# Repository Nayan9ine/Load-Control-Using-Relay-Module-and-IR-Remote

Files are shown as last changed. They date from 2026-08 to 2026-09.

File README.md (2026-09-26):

# Load-Control-Using-Relay-Module-and-IR-Remote 
 
<p align="right">-By Nayan Ag</p>
Created a load control system in which load connected to relay module is turned ON or OFF on entering a password with IR based remote.Built on arduin UNO R3 clone using CH340 chip.
<br><br>
Compo used: IR Receiver; Arduino UNO CH340; Relay Module; Remote with IR transmitter; LCD with I2C ;Load; Jumper cables and 5v cable.

<table>
  <tr>
    <td>
    <br>  <div  align="center"><sub><i> Fig1:Setup Box</i></sub></div>
</td>
    <td>
    <br>  <div  align="center"><sub><i> Fig2: IR receiver on Setup Box</i></sub></div>
</td>
    <td>
    <br><div align="center"><sub><i> Fig3: IR receiver Desoldered</i></sub></div>
</td>
  </tr>
</table>

IR receiver was salvaged off from old dish tv setup box . Has 3 pins with signal,gnd,power starting from left to right respectively. Required a lot of heat and flux to de-solder, ultimately leading to a pin breaking. I soldered jumper cables hastily to it and used shrink tubes. 
<br>

<table>
  <tr>
    <td>
    <br>  <div  align="center"><sub><i> Fig4: IR Receiver</i></sub></div>
</td>
    <td>
    <br>  <div  align="center"><sub><i> Fig5: LDO on Setup Box</i></sub></div>
</td>
    <td>
    <br><div align="center"><sub><i> Fig6: LD1117AG ADA TBTQ</i></sub></div>
</td>
  </tr>
</table>
Finding IR Polarity: Since the setup box wasn’t working, I couldn’t directly measure using multimeter. So I found the component responsible for stepping down which is usually kept near for EMI reduction which is shown in the picture LD1117AG ADA TBTQ. It is a Low Dropout (LDO) linear positive voltage regulator manufactured by UTC (Unisonic Technologies). I compared the connection of IR and LDO with LDO and Barrel jack Input of the circuit. Ground was common to all and the one pin of IR not showing any continuity with LDO was the signal pin hence remains the power pin.<br><br>
Using Library: Used IRremote library by Shirriff, z3t0, ArminJo (https://github.com/Arduino-IRremote/Arduino-IRremote). The library can detect numerous protocols used for communication by IR. Standard rgb light control Remote was used that uses NEC protocol. The library helped identify signal protocol and command code for each button pressed.
<br><br>

<p align="center">
  
   <div align="center"><sub><i> Fig7:Finding Remote Codes</i></sub></div>
</p>   


<div align="center"><sub><i> Fig8:NEC Protocol Used by Remote</i></sub></div>
<br>
Code was adjusted so that it integrates relay, LCD and assigning buttons values with numbers and letters. Removed or commented various sections of original code that was unnecessary after I found out my remote’s protocol.

<br><br>
<p align="center"><br><sub><i>Fig9:RGB Remote</i></sub></p>

<br><br>

<p align="center"><sub><i>Fig10:Remote Button Codes</i></sub></p>

<br><br>
2 passwords declared in code one to turn relay on and other to turn off. Delay() of any value was causing timing issue hence leading to frozen response of lcd or ir. Baud rate of 115200 was utilized. Code only uploads when set back to 9600 for some reason and then turned back to 115200(I think it has something to do with CH340 chip). Millis() was used to debounce the buttons. LCD with I2C used to show the status of relay and password entered. Backlight pins connected with 220ohm resistor and also LCD was supplied with separate 5v to reduce current draw.LCD connected with separate source with gnd common for both ext src and Arduino as sda and sdl do require gnd for reference.A USB A plug was stripped and power and gnd wire connected to IR.

<br>
<table>
  <tr>
    <td>
    <br>  <div  align="center"><sub><i> Fig11 :5v USB A Plug</i></sub></div>
</td>
    <td>
    <br>  <div  align="center"><sub><i> Fig12 :5v USB A Plug</i></sub></div>
</td>
  </tr>
</table>

Current req: relay: 70-80mA per channel to energize the coil and 2-20mA to power the IR led in optocoupler, LCD backlight: 20-50mA, Arduino can provide : 400-450mA by USB ,500-800 by barrel jack (7v-12v).IR receiver 3.3v: 0.4-1.5ma on standby and 3-5mA at peak. During switching of relay rapid current burst occurs that causes fluctuation in LCD causing dim text appearance (due to voltage drop?). To counter that capacitor can be used to be placed in parallel and delayed activation of LCD relay status indicator or in my case I used a totally separate source. 

<br><br>

<br><p align="center"> <sub><i>Fig13: Entire Setup (1)</i></sub>

<br><br>

<p align="center"> <sub><i>Fig14: Entire Setup (2)</i></sub></p>

<br>
<table>
  <tr>
    <td>
    <br>  <div  align="center"><sub><i> Fig15 :Turning ON</i></sub></div>
</td>
    <td>
    <br>  <div  align="center"><sub><i> Fig16 :Bulb is ON</i></sub></div>
</td>
  </tr>
</table>

<table>
  <tr>
    <td>
    <br>  <div  align="center"><sub><i> Fig17 :Turning OFF/i></sub></div>
</td>
    <td>
    <br>  <div  align="center"><sub><i> Fig18 :Bulb OFF</i></sub></div>
</td>
  </tr>
</table>

<table>
  <tr>
    <td>
    <br>  <div  align="center"><sub><i> Fig19 :Wrong Pass Used</i></sub></div>
</td>
    <td>
    <br>  <div  align="center"><sub><i> Fig20 :"RE-ENTER" Displayed</i></sub></div>
</td>
  </tr>
</table>
Kicad Document Images:<br>
Relay module was extracted from (https://github.com/ampnics/Relay-Module-HW-Design).<br>
Screenshot (1045)<br>
Screenshot (1042)<br>
Screenshot (1044)<br>
Screenshot (1043)
<br>
WHAT I LEARNED: Serial.println(F("2")); use of F? F stores memory in Flash instead of using the 2kb SRAM (Save Dynamic Memory) in Arduino UNO and as the code prints a lot of static texts we use flash memory. Variables that change shouldn’t be placed in flash as they need to be in SRAM to be updated.
<br><br>
Flash memory is permanent memory stored in Arduino. It stores the code even when unplugged. Static Variables stored in flash using F() macro.
<br><br>
In SRAM: there is stack and heap in a single memory column. Stack stores function call names and local variables and grows downwards. Heap stores dynamically stored data and grows upward. When memory gets full (called ‘stack overflow’) they both collide into each other and try overwriting each other causing random Arduino reboots and garbage outputs.
<br><br>
Possible Updates: password using cloud/wifi; buzzer integration for audio feedback; circuit need to be made cleaner.

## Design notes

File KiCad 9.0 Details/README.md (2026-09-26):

This file includes what was learnt during PCB making process in KiCad.
---
MADE ARDUINO SHIELD FOR LOAD CONTROL which has relay module IR receiver and LCD display embedded on it with a pot to control brightness.<br><br>
->Learnt how to adjust arduino shield boundary layer to fit in components.<br><br>
->How to use VIAS,Net Labels, Power FLags<br><br>
->power GND symbols act as global labels so symbols with same name so get connected electrically. <br><br>
->re matching pin reference numbers to their footprints<br><br>
->Arduino sheild template was used, the entire boundary was fixed in one place.Was unable to expand the area to put my components in. Learnt about the "locked" feature and disabled it by using Appearance tab and Selection Filter.  <br><br>
->used fillet lines to round up sharp wire edges.<br><br>
->to draw board outline: appearance->layers->Edge.Cuts -> choose drawing line or shape etc.<br><br>
->changing sda/scl pins from digital to analog side in order for better routing<br><br>
->using analog pin as digital for IR receiver for better routing<br><br>
-> can keep signal traces (i2c scl sda) thin but keep them away from high freq signals (buck converter)
or relay module as they create heavy EMI. Never run them parallel to relay lines, cross only at 90 degrees to relay lines)<br><br>
->signal lines: 0.2mm Power lines:0.4mm GND lines: 0.6mm<br><br>
Appropriate Components Found:<br><br>
-> RELAY MODULE DESIGN EXTRACTED from: (https://github.com/ampnics/Relay-Module-HW-Design) when copy-pasted from original schematic the resulting pcb desin was jumbled up so directly copy-pasted PCB design and chenaged the reference name to match the schematic so duplicate relay components won't be created again. <br><br>  
->The LCD I2C component I was able to find (EA T123X-I2C)  was different than what was used in the project. It needed 2 4.7k Ohm pull up resistors for SDA,SCL. Has 2 additional pins for adjusting display contrast (Vo and Vlcd). The contrast was controlled by a potentiometer with Vlcd connected to gnd and 3rd pin of pot. 2nd pin to Vo and 1st to Vdd (5v).
<br><br>
->Added 2 pwr flags on Vo and Vdd as kicad ERC was throwing "input power pins not connected to source" error.<br><br>
->made several connections using NET LABELS to avoid messy wiring.<br><br>
->added no connect flags on pins not being used.<br><br>
-> Mounting holes added to show LCD external 5V supply and AC load connection to relay thorugh a LAMP symbol.<br><br>
->Since GND pins in arduino shield are assumed to be internally connected, KiCad ERC throws "No connection" error and DRC shows unecessary ratnets. So I had to change the name of various GND symbols and some labelled as No Connect.<br><br>
->For smd resistors only traces in front can get connected so used vias to turn back trace into front then connect to smd.

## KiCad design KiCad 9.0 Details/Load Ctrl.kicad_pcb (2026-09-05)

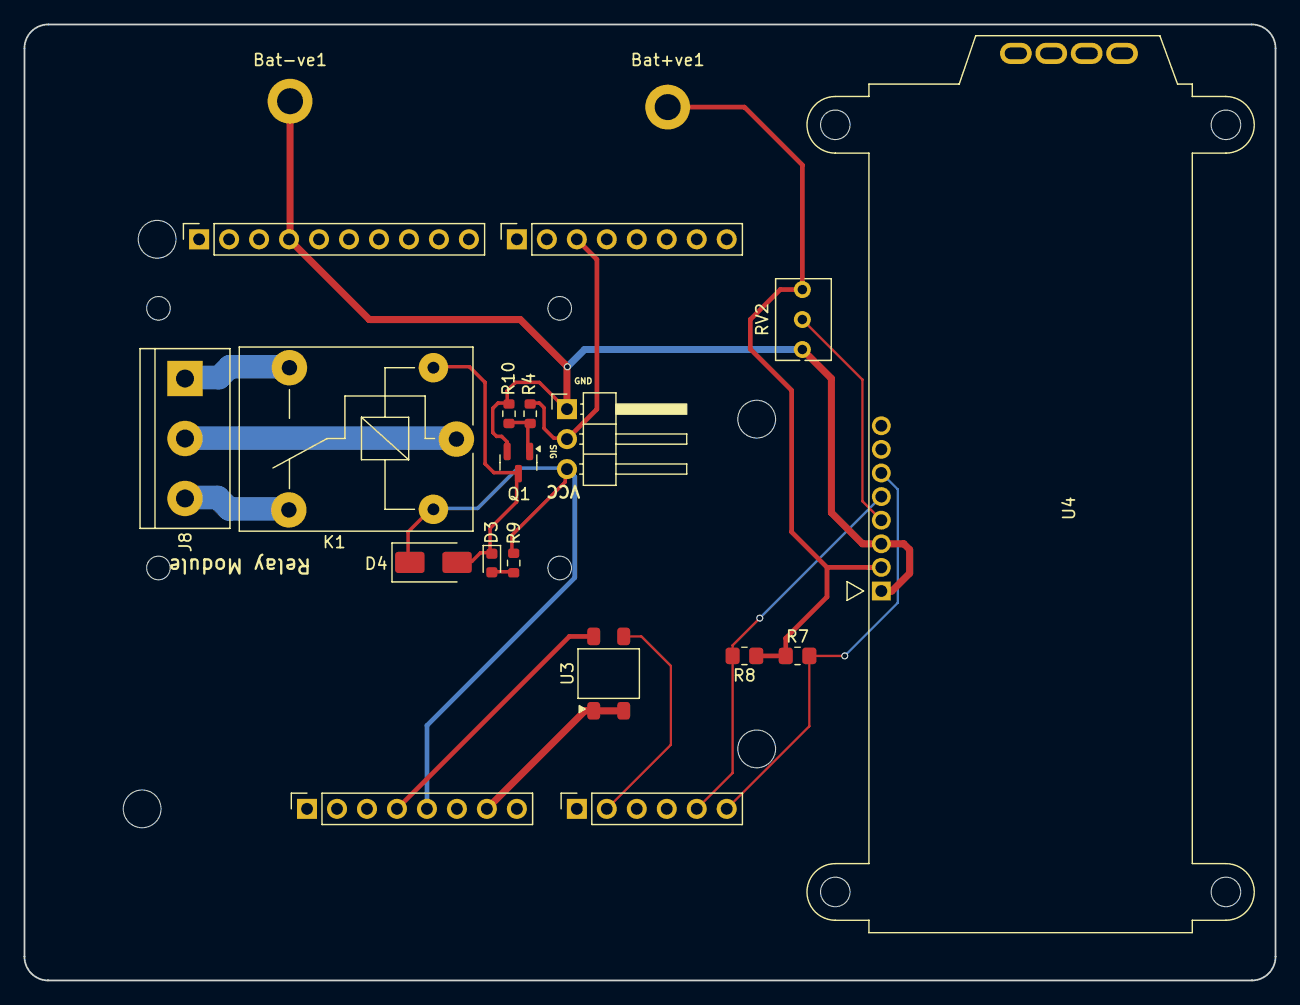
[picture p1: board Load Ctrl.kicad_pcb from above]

Board: 2 copper layers, 106.0 x 81.0 mm, 24 parts (0 on the bottom side), 16 nets.

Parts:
Bat+ve1: MountingHole_Pad; MountingHole_2.2mm_M2_DIN965_Pad
Bat-ve1: MountingHole_Pad; MountingHole_2.2mm_M2_DIN965_Pad
D3: LED; LED_0603_1608Metric
D4: MRA4003T3G; D_SMA
J1: Power; PinSocket_1x08_P2.54mm_Vertical
J2: Digital/PWM; PinSocket_1x10_P2.54mm_Vertical
J3: Analog; PinSocket_1x06_P2.54mm_Vertical
J4: Digital/PWM; PinSocket_1x08_P2.54mm_Vertical
J7: Conn_01x03_Pin; PinHeader_1x03_P2.54mm_Horizontal
J8: Screw_Terminal_01x03; TerminalBlock_bornier-3_P5.08mm
K1: SANYOU_SRD_Form_C; Relay_SPDT_SANYOU_SRD_Series_Form_C
MH1, MH2, MH3, MH4: MountingHole_3.2mm
Q1: MMBT2222A; SOT-23
R4: 1K; R_0603_1608Metric
R7, R8: 4.7K; R_0805_2012Metric_Pad1.20x1.40mm_HandSolder
R9, R10: 10K; R_0603_1608Metric
RV2: Potentiometer; Potentiometer_Bourns_3266Y_Vertical
U3: IRM-H6xxT; Everlight_IRM-H6xxT
U4: EA_T123X-I2C; NHD-C0220BiZ-FSRGB

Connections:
+3V3: J1.4, U3.4 (Vcc)
+5V: D4.1 (K), J1.5, J7.3, K1.5, R9.1
/A1: J3.2, U3.3 (OUT)
/SCL/A5: J3.6, R7.2, U4.6 (SCL)
/SDA/A4: J3.5, R8.2, U4.5 (SDA)
/SIG: J4.3, J7.2, R4.1
/Vdd: Bat+ve1.1, R7.1, R8.1, RV2.1, U4.2 (VDD)
GND: Bat-ve1.1, J2.4, J7.1, Q1.2 (E), R10.2, RV2.3, U4.1 (VSS), U4.3 (VLCD)
GND1: J1.7, U3.1 (GND), U3.2 (GND)
unnamed: D3.2 (A), R9.2
unnamed: D3.1 (K), D4.2 (A), K1.2, Q1.3 (C)
unnamed: J8.1, K1.3
unnamed: J8.2, K1.1
unnamed: J8.3, K1.4
unnamed: Q1.1 (B), R4.2, R10.1
unnamed: RV2.2, U4.4 (V0)

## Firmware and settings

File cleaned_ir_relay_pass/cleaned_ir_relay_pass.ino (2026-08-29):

//WORKS!!

#include <Arduino.h>
/*
 * Specify which protocol(s) should be used for decoding.
 * If no protocol is defined, all protocols (except BEO / Bang&Olufsen) are active.
 * This must be done before the #include <IRremote.hpp>
 * In alphabetic order
 */
//#define DECODE_DENON        // Includes Sharp - requires around 250 bytes of program memory on ATmega328
//#define DECODE_JVC          // ~ 200 bytes
//#define DECODE_KASEIKYO     // Includes Panasonic ~ 300 bytes
//#define DECODE_LG           // ~ 400 bytes
//#define DECODE_NEC          // Includes Apple and Onkyo ~ 250 bytes
//#define DECODE_SAMSUNG      // ~ 300 bytes
//#define DECODE_SONY         // ~ 175 bytes
//#define DECODE_RC5          // RC5 + MARANTZ: ~ 425 bytes
//#define DECODE_RC6          // ~ 375 bytes

// Universal protocol decoder
//#define DECODE_DISTANCE_WIDTH // Universal decoder for pulse distance width protocols ~ 2275 bytes
//#define DECODE_HASH         // special decoder for all protocols ~ 250 bytes

// Exotic protocol decoder
//#define DECODE_BOSEWAVE     // ~ 140 bytes
//#define DECODE_FAST         // ~ 135 bytes
//#define DECODE_LEGO_PF      // ~ 300 bytes
//#define DECODE_MAGIQUEST    // ~ 270 bytes
//#define DECODE_MARANTZ      // RC5 + MARANTZ: ~ 425 bytes
//#define DECODE_OPENLASIR    // Modified NEC with 8-bit validated address + 16-bit command. ~ 175 bytes
//#define DECODE_WHYNTER      // ~ 90 bytes

//#define DECODE_BEO          // This protocol must always be enabled manually, i.e. it is NOT enabled if no protocol is defined. It prevents decoding of SONY! ~ 430 bytes

//#define DEBUG               // Activate this for lots of lovely debug output from the decoders.

//#define RAW_BUFFER_LENGTH  750 // For air condition remotes it may require up to 750. Default is 200.

//adding LCD

#include <Wire.h>
#include <LiquidCrystal_I2C.h>
LiquidCrystal_I2C lcd(0x27, 16, 2);
//Adding millis to code (check if cause timing problems)
byte delay_time=50;
unsigned long curr_time=0;
unsigned long prev_time=0;

//RELAY controlled by IR remote (My Relay Module is Active Low)
#define Relay_ON LOW
#define Relay_OFF HIGH
byte relay_pin=8;

//password
String pass="ABCD";  //ON
String off="1234";   //OFF
String entered="";   //STORES USER INPUT


//#define DECODE_NEC          // Includes Apple and Onkyo ~ 250 bytes
//#define DECODE_RC5          // RC5 + MARANTZ: ~ 425 bytes
//#define DECODE_OPENLASIR    // Modified NEC with 8-bit validated address + 16-bit command. ~ 175 bytes
//#define RAW_BUFFER_LENGTH  750 // For air condition remotes it may require up to 750. Default is 200.

#include "PinDefinitionsAndMore.h" // Define macros for input and output pin etc. Sets FLASHEND and RAMSIZE and evaluates value of SEND_PWM_BY_TIMER.
#define DECODE_NEC
#include <IRremote.hpp> // include the library

void setup() {
    Serial.begin(9600);
    Serial.println("Running at 9600");
    Serial.flush(); // Blocks until all outgoing characters have been sent
    Serial.begin(115200);
    //LCD
    lcd.init();
    lcd.backlight();
    // pinMode(bl, OUTPUT); use PWM for dimming or external resistor (NOT FOR ONES WITH I2C)
    // analogWrite(bl,150);
    lcd.setCursor(0, 0);
    lcd.print("RELAY: OFF");
    lcd.setCursor(0, 1);
    lcd.print("PASS :");
    // relay
   digitalWrite(relay_pin,Relay_OFF);
   pinMode(relay_pin,OUTPUT);
   digitalWrite(relay_pin,Relay_OFF);
   
   // Just to know which program is running on my Arduino
   // Serial.println(F("START " __FILE__ " from " __DATE__ "\r\nUsing library version " VERSION_IRREMOTE));

    // Start the receiver and if not 3. parameter specified, take LED_BUILTIN pin from the internal boards definition as default feedback LED
    IrReceiver.begin(IR_RECEIVE_PIN, ENABLE_LED_FEEDBACK);

    Serial.print(F("Ready to receive IR signals of protocols: "));
    // printActiveIRProtocols(&Serial); // Requires additional 318 bytes program memory
    // Serial.println(F("at pin " STR(IR_RECEIVE_PIN)));
}

void loop() {
    if (IrReceiver.decode()) {    
        if (IrReceiver.decodedIRData.protocol == UNKNOWN) {
            //Serial.println(F("Received noise or an unknown (or not yet enabled) protocol"));
            // We have an unknown protocol here, print extended info
            //IrReceiver.printIRResultRawFormatted(&Serial, true);

            IrReceiver.resume(); // Do it here, to preserve raw data for printing with printIRResultRawFormatted()
        } else {
            IrReceiver.resume(); // Early enable receiving of the next IR frame

            // IrReceiver.printIRResultShort(&Serial);   // Requires additional 1436 bytes program memory
            // IrReceiver.printIRSendUsage(&Serial);     // Calls printIRResultShort() and other functions, if protocol is UNKNOWN
        }
        //Serial.println();

         //Finally, check the received data and perform actions according to the received command
         
        if (IrReceiver.decodedIRData.flags & IRDATA_FLAGS_IS_REPEAT) {
            //Serial.println(F("Repeat received. Here you can repeat the same action as before."));
        } 
        else {
          curr_time = millis();  
          //used IrReceiver.resume(); after every data received and processed to free up the buffer and activate receiver
          //"entered" variable stores user input and has no length limit,so enter button created.                    
            if (IrReceiver.decodedIRData.command == 0x1) {
                if (curr_time-prev_time>=delay_time){
                Serial.println(F("A"));
                lcd.setCursor(8,1); //8+i adjusts cursor accordingly to number of inputs already received from user 
                // do something else
                entered=entered+"A";
                lcd.print(entered);
                prev_time=curr_time;
                IrReceiver.resume();
                }

            } else if (IrReceiver.decodedIRData.command == 0x2) {
                if (curr_time-prev_time>=delay_time){
                Serial.println(F("B"));
                lcd.setCursor(8,1);

                entered=entered+"B";
                lcd.print(entered);
                prev_time=curr_time;
                IrReceiver.resume();
                }
            }
            else if (IrReceiver.decodedIRData.command == 0x3) {
                if (curr_time-prev_time>=delay_time){
                Serial.println(F("C"));
                lcd.setCursor(8,1);
                
                entered=entered+"C";
                lcd.print(entered);
                prev_time=curr_time;
                IrReceiver.resume();
                }
            }
            else if (IrReceiver.decodedIRData.command == 0x4) {
                if (curr_time-prev_time>=delay_time){
                Serial.println(F("D"));
                lcd.setCursor(8,1);
                
                entered=entered+"D";
                lcd.print(entered);
                prev_time=curr_time;
                IrReceiver.resume();
                }
            }
            else if (IrReceiver.decodedIRData.command == 0x5) {
                if (curr_time-prev_time>=delay_time){
                Serial.println(F("1"));
                lcd.setCursor(8,1);
                
                entered=entered+"1";
                lcd.print(entered);
                prev_time=curr_time;
                IrReceiver.resume();
                }
            }
            else if (IrReceiver.decodedIRData.command == 0x6) {
                if (curr_time-prev_time>=delay_time){
                Serial.println(F("2"));
                lcd.setCursor(8,1);
                
                entered=entered+"2";
                lcd.print(entered);
                prev_time=curr_time;
                IrReceiver.resume();
                }
            }
            else if (IrReceiver.decodedIRData.command == 0x7) {
                if (curr_time-prev_time>=delay_time){
                Serial.println(F("3"));
                lcd.setCursor(8,1);
                
                entered=entered+"3";
                lcd.print(entered);
                prev_time=curr_time;
                IrReceiver.resume();
                }
            }
            else if (IrReceiver.decodedIRData.command == 0x8) {
                if (curr_time-prev_time>=delay_time){
                Serial.println(F("4"));
                lcd.setCursor(8,1);
                               
                entered=entered+"4";
                lcd.print(entered);
                prev_time=curr_time;
                IrReceiver.resume();
                }
            }
            else if (IrReceiver.decodedIRData.command == 0x9) {
                if (curr_time-prev_time>=delay_time){
                Serial.println(F("5"));
                lcd.setCursor(8,1);
                               
                entered=entered+"5";
                lcd.print(entered);
                prev_time=curr_time;
                IrReceiver.resume();
                }
            }
            else if (IrReceiver.decodedIRData.command == 0xA) {
                if (curr_time-prev_time>=delay_time){
                Serial.println(F("6"));
                lcd.setCursor(8,1);
                               
                entered=entered+"6";
                lcd.print(entered);
                prev_time=curr_time;
                IrReceiver.resume();
                }
            }
            else if (IrReceiver.decodedIRData.command == 0xB) {
                if (curr_time-prev_time>=delay_time){
                Serial.println(F("7"));
                lcd.setCursor(8,1);
                              
                entered=entered+"7";
                lcd.print(entered);
                prev_time=curr_time;
                IrReceiver.resume();
                }
            }
            else if (IrReceiver.decodedIRData.command == 0xC) {
                if (curr_time-prev_time>=delay_time){
                Serial.println(F("8"));
                lcd.setCursor(8,1);
                
                entered=entered+"8";
                lcd.print(entered);
                prev_time=curr_time;
                IrReceiver.resume();
                }
            }
            else if (IrReceiver.decodedIRData.command == 0xD) {
                if (curr_time-prev_time>=delay_time){
                Serial.println(F("9"));
                lcd.setCursor(8,1);
                
                
                entered=entered+"9";
                lcd.print(entered);
                prev_time=curr_time;
                IrReceiver.resume();
                }
            }
            else if (IrReceiver.decodedIRData.command == 0xE) {
                if (curr_time-prev_time>=delay_time){
                Serial.println(F("0"));
                lcd.setCursor(8,1);
                
                entered=entered+"0";
                lcd.print(entered);
                prev_time=curr_time;
                IrReceiver.resume();
                }
            }    
        
          if (IrReceiver.decodedIRData.command == 0xF) { // "Strobe" button acts as Enter.
            if (curr_time-prev_time>=delay_time){
              if (pass==entered){
                lcd.setCursor(7, 0);
                lcd.print("ON      "); //space to remove 'F' from 'OFF'               
                digitalWrite(relay_pin,Relay_ON);
                Serial.println("Relay turned ON");
                Serial.println(entered);
                }
              if(entered==off){
                digitalWrite(relay_pin,Relay_OFF);
                Serial.println("Relay turned OFF");
                Serial.println(entered);
                lcd.setCursor(7, 0);
                lcd.print("OFF     ");
                }           
              if (pass!=entered && off!=entered){
                Serial.println("Wrong Password!");
                lcd.setCursor(7, 0);
                lcd.print("RE-ENTER");
                }
              lcd.setCursor(8, 1);
              lcd.print("        ");  
              entered="";
              prev_time=curr_time;
              IrReceiver.resume();
            }
          }
        }        
    }
}

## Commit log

2026-09-05 Create KiCad : What was done
2026-09-05 Update and rename KiCad : What was done to KiCad
2026-09-07 Create README.md
    Details on how the kicad pcb was made and what was learned.
2026-09-07 Add files via upload
    kicad docs
    [Load Ctrl.kicad_pcb, Load Ctrl.kicad_sch]
